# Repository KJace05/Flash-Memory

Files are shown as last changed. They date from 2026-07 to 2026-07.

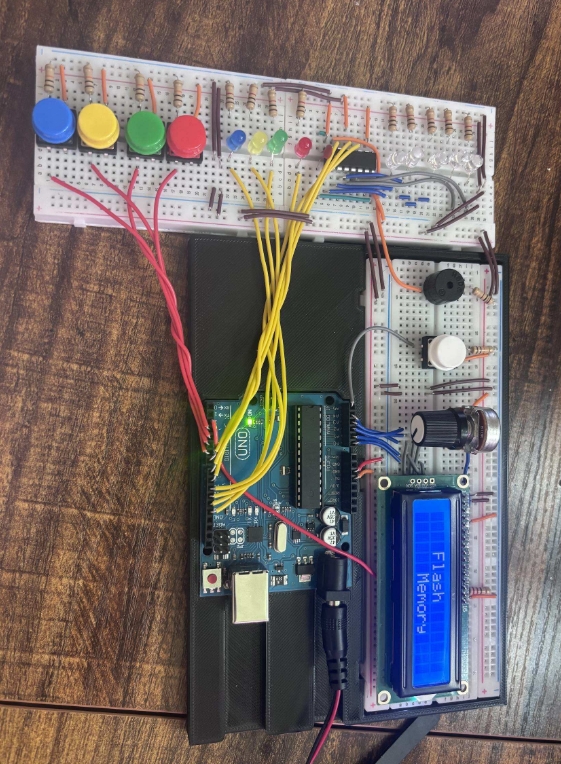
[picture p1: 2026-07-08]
content/breadboard overview.jpeg

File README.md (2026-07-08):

# Flash Memory

> An Arduino-based memory game inspired by Simon Says — built with C++ for the Arduino Uno.

## About

Flash Memory challenges players to watch a randomly generated sequence of colored LED flashes and recreate it by pressing the matching colored buttons in the correct order. The sequence grows longer with each level, testing both memory and focus.

A buzzer sounds with every LED flash during the sequence display, giving players an audio cue to count flashes by ear alongside the visual pattern.

---

##  Gameplay

1. **Watch** — colored LEDs flash a random sequence with an accompanying buzzer beep per flash
2. **Repeat** — press the matching colored buttons in the same order
3. **Progress** — complete the sequence correctly to advance to the next level
4. **Win** — complete all 5 levels

### Wrong Guess
- All 4 colored LEDs flash simultaneously
- Buzzer sounds to signal the incorrect answer
- A short delay prevents further input
- The same sequence replays automatically — unlimited attempts per level

### Replay Button
Forgot the sequence mid-guess? Press the dedicated replay button at any time during the input phase to rewatch the same sequence without generating a new one.

---

##  Levels

| Level | Sequence Length | Progress LED |
|---|---|---|
| 1 | 2 flashes | ⚪ |
| 2 | 3 flashes | ⚪⚪ |
| 3 | 4 flashes | ⚪⚪⚪ |
| 4 | 5 flashes | ⚪⚪⚪⚪ |
| 5 | 6 flashes | ⚪⚪⚪⚪⚪ |

Five white LEDs connected to a 74HC595 shift register light up one by one as each level is completed, giving a persistent visual indicator of progress.

---

## Randomization

Every game generates a unique sequence using the Arduino `EEPROM` library as a persistent seed generator. On each power cycle, the stored seed is read, incremented, and written back, ensuring a different sequence every playthrough, even across power cycles.

---

## Hardware

| Component | Quantity | Notes |
|---|---|---|
| Arduino Uno | 1 | Microcontroller |
| Colored LEDs | 4 | Red, Green, Yellow, Blue |
| Colored buttons | 4 | Matching colors |
| White LEDs | 5 | Level progress indicator |
| 74HC595 shift register | 1 | Drives white LEDs + buzzer |
| Active buzzer | 1 | Connected to Q0 on shift register |
| 16x2 LCD display | 1 | Shows title and game state |
| Replay button | 1 | Replays current sequence |
| Resistors | Various | Current limiting for LEDs |
| Potentiometer | 1 | Controls LCD brightness

---

##  Pin Map

| Pin | Assignment |
|-----|---|
| `2` | LCD D7 |
| `3` | Blue button |
| `4` | Yellow button |
| `5` | Green button |
| `6` | Red button |
| `7` | 74HC595 Clock |
| `8` | 74HC595 Latch |
| `9` | 74HC595 Data |
| `10` | Red LED |
| `11` | Green LED |
| `12` | Yellow LED |
| `13` | Blue LED |
| `A0` | LCD RS |
| `A1` | LCD Enable |
| `A2` | LCD D4 |
| `A3` | LCD D5 |
| `A4` | LCD D6 |
| `A5` | Replay button |

### 74HC595 Output Map
| Bit | Assignment |
|-----|---|
| Q0 | Buzzer |
| Q1–Q5 | White LEDs 1–5 |
| Q6–Q7 | Unused |

---

## Libraries

```cpp
#include <LiquidCrystal.h>   // LCD display control
#include <EEPROM.h>           // Persistent seed storage for randomization
```

---

## Technical Notes

- Sequence timing uses **`millis()`** for non-blocking LED flashing — the Arduino remains responsive during the display phase
- **`delay()`** is used selectively to gate player input at key moments (wrong guess lockout, level transition pause)
- The buzzer and white LEDs share the same 74HC595 — all shift register writes preserve the full byte state to prevent unintentional outputs
- `EEPROM.get()` / `EEPROM.put()` store a 4-byte `unsigned long` seed (0 to ~4 billion) for maximum sequence variety

---

## Getting Started

1. Wire components according to the pin map above
2. Install the Arduino IDE
3. Open `FlashMemory.ino`
4. Select **Arduino Uno** as the board
5. Upload and play

---

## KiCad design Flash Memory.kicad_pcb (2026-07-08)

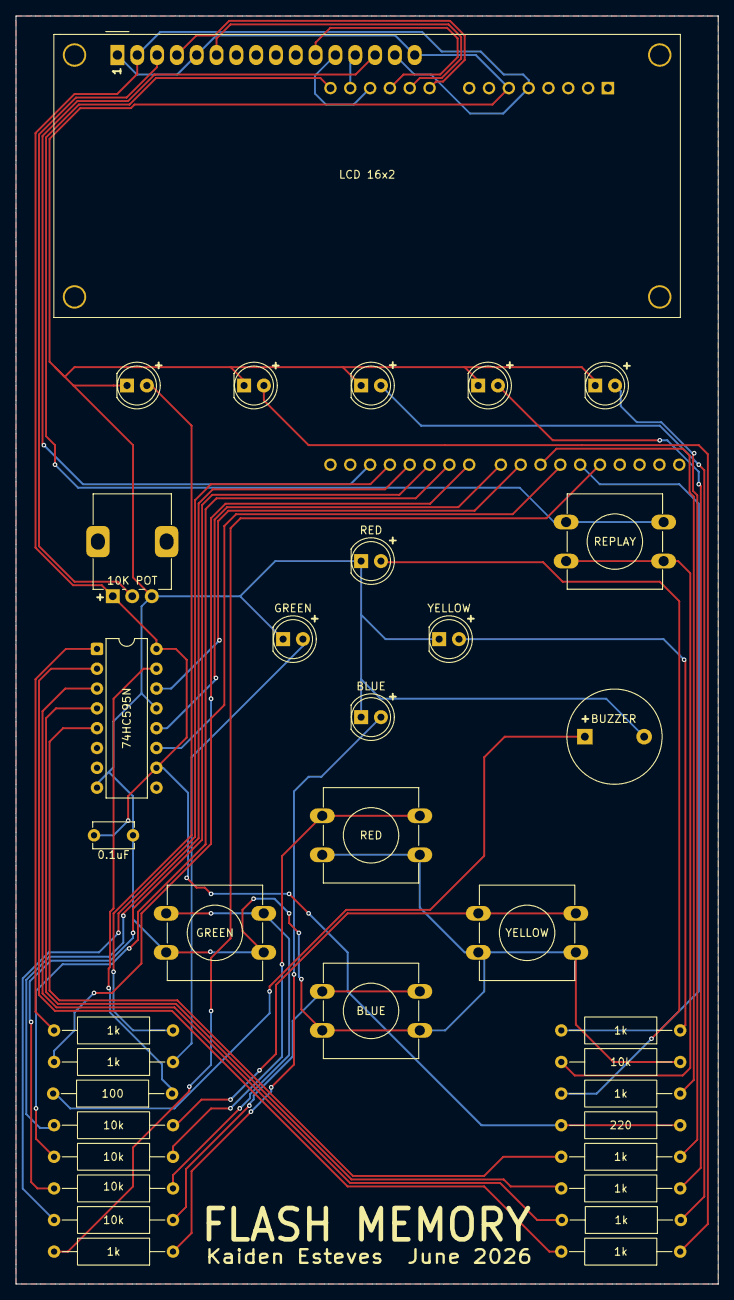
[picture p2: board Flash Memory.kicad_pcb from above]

Board: 2 copper layers, 90.0 x 162.5 mm, 36 parts (1 on the bottom side), 42 nets.

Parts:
74HC595N: 74HC595; DIP-16_W7.62mm
Arduino1: Arduino_UNO_R3
BLUE: LED; LED_D5.0mm
BUZZER: Buzzer; Buzzer_12x9.5RM7.6
Button_B1: SW_Push; SW_PUSH-12mm
Button_G1: SW_Push; SW_PUSH-12mm
Button_R1: SW_Push; SW_PUSH-12mm
Button_Y1: SW_Push; SW_PUSH-12mm
C1: .1uf; C_Disc_D5.1mm_W3.2mm_P5.00mm
GREEN: LED; LED_D5.0mm
LCD 16x2: WC1602A
Level_1, Level_2, Level_3, Level_4, Level_5: LED; LED_D5.0mm
Potentiometer1: R_Potentiometer; Potentiometer_Alps_RK09K_Single_Vertical
RED: LED; LED_D5.0mm
REPLAY: SW_Push; SW_PUSH-12mm
YELLOW: LED; LED_D5.0mm
r_blue1: 1k; R_Axial_DIN0309_L9.0mm_D3.2mm_P15.24mm_Horizontal
r_butt_blue1: 10k; R_Axial_DIN0309_L9.0mm_D3.2mm_P15.24mm_Horizontal
r_butt_green1: 10k; R_Axial_DIN0309_L9.0mm_D3.2mm_P15.24mm_Horizontal
r_butt_red1: 10k; R_Axial_DIN0309_L9.0mm_D3.2mm_P15.24mm_Horizontal
r_butt_yellow1: 10k; R_Axial_DIN0309_L9.0mm_D3.2mm_P15.24mm_Horizontal
r_buzz1: 100; R_Axial_DIN0309_L9.0mm_D3.2mm_P15.24mm_Horizontal
r_green1: 1k; R_Axial_DIN0309_L9.0mm_D3.2mm_P15.24mm_Horizontal
r_l1, r_l2, r_l3, r_l4, r_l5: 1k; R_Axial_DIN0309_L9.0mm_D3.2mm_P15.24mm_Horizontal
r_pot1: 220; R_Axial_DIN0309_L9.0mm_D3.2mm_P15.24mm_Horizontal
r_red1: 1k; R_Axial_DIN0309_L9.0mm_D3.2mm_P15.24mm_Horizontal
r_replay1: 10k; R_Axial_DIN0309_L9.0mm_D3.2mm_P15.24mm_Horizontal
r_yellow1: 1k; R_Axial_DIN0309_L9.0mm_D3.2mm_P15.24mm_Horizontal

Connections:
+5V: 74HC595N.10 (~SRCLR), 74HC595N.16 (VCC), Arduino1.5 (+5V), C1.1, LCD 16x2.2 (VDD), LCD 16x2.15 (LED(+)), Potentiometer1.1, r_pot1.1, r_pot1.2
GND: 74HC595N.8 (GND), 74HC595N.13 (~OE), Arduino1.6 (GND), BLUE.1 (K), BUZZER.2 (-), Button_B1.2, Button_G1.2, Button_R1.2, Button_Y1.2, C1.2, GREEN.1 (K), LCD 16x2.1 (VSS), LCD 16x2.5 (R/W), LCD 16x2.16 (LED(-)), Level_1.1 (K), Level_2.1 (K), Level_3.1 (K), Level_4.1 (K), Level_5.1 (K), Potentiometer1.3, RED.1 (K), YELLOW.1 (K), r_replay1.1
unnamed: Arduino1.9 (A0), LCD 16x2.4 (RS)
unnamed: Arduino1.10 (A1), LCD 16x2.6 (E)
unnamed: Arduino1.11 (A2), LCD 16x2.11 (D4)
unnamed: Arduino1.12 (A3), LCD 16x2.12 (D5)
unnamed: Arduino1.17 (D2), LCD 16x2.14 (D7)
unnamed: Arduino1.18 (D3), r_butt_blue1.2
unnamed: Arduino1.19 (D4), r_butt_yellow1.2
unnamed: Arduino1.20 (D5), r_butt_green1.2
unnamed: Arduino1.21 (D6), r_butt_red1.2
unnamed: 74HC595N.11 (SRCLK), Arduino1.22 (D7)
unnamed: 74HC595N.12 (RCLK), Arduino1.23 (D8)
unnamed: 74HC595N.14 (SER), Arduino1.24 (D9)
unnamed: Arduino1.25 (D10), r_red1.1
unnamed: Arduino1.26 (D11), r_green1.2
unnamed: Arduino1.27 (D12), r_yellow1.2
unnamed: Arduino1.28 (D13), r_blue1.2
unnamed: Arduino1.14 (SCL/A5), REPLAY.1
unnamed: BUZZER.1 (+), r_buzz1.2
unnamed: BLUE.2 (A), r_blue1.1
unnamed: Button_B1.1, r_butt_blue1.1
unnamed: Button_G1.1, r_butt_green1.1
unnamed: Button_R1.1, r_butt_red1.1
unnamed: Button_Y1.1, r_butt_yellow1.1
unnamed: GREEN.2 (A), r_green1.1
unnamed: 74HC595N.15 (QA), r_buzz1.1
unnamed: 74HC595N.1 (QB), r_l1.2
unnamed: 74HC595N.2 (QC), r_l2.2
unnamed: 74HC595N.3 (QD), r_l3.2
unnamed: 74HC595N.4 (QE), r_l4.2
unnamed: 74HC595N.5 (QF), r_l5.2
unnamed: Arduino1.13 (SDA/A4), LCD 16x2.13 (D6)
unnamed: LCD 16x2.3 (VO), Potentiometer1.2
unnamed: Level_1.2 (A), r_l1.1
unnamed: Level_2.2 (A), r_l2.1
unnamed: Level_3.2 (A), r_l3.1
unnamed: Level_4.2 (A), r_l4.1
unnamed: Level_5.2 (A), r_l5.1
unnamed: RED.2 (A), r_red1.2
unnamed: REPLAY.2, r_replay1.2
unnamed: YELLOW.2 (A), r_yellow1.1

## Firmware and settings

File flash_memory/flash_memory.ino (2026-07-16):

#include <LiquidCrystal.h>
#include <EEPROM.h>

// Button initalization
#define R_BUTT_PIN 6
#define G_BUTT_PIN 5
#define Y_BUTT_PIN 4
#define B_BUTT_PIN 3
#define REPLAY_BUTT_PIN A5


// LED initalization
#define R_LED 10
#define G_LED 11
#define Y_LED 12
#define B_LED 13


// IC LED & Buzzer initalization
#define IC_LEVEL_DATA 9
#define IC_LEVEL_LATCH 8
#define IC_LEVEL_CLOCK 7


// setting up game state for main loop
enum GameState {SHOW_SEQUENCE, WAIT_FOR_INPUT, LEVEL_COMPLETE, GAME_WON}; // for switch statement
GameState state_of_game = SHOW_SEQUENCE; //begin at showing sequence


//colored LEDS
int colored_leds[] = {10,11,12,13}; // colored LEDS
int level = 0; // start on level 1
bool level_over = false;
int total_flashing = 2; // initally, 2LEDS will flash. 6 max
int sequence[6] = {};
bool sequence_made = false;
int flash_index = 0;
bool led_on = false;
unsigned long last_LED_flash = millis();
unsigned long flash_delay = 300;


// White LEDS
int level_leds[] = {1,2,3,4,5};
int level_led = 1;


// BUTTONS
int buttons[] = {6,5,4,3}; //buttons
unsigned long last_debounce_time[4] = {0,0,0,0};
unsigned long debounce_delay = 25;
bool button_state[4] = {LOW,LOW,LOW,LOW};
bool last_button_state[4] = {LOW,LOW,LOW,LOW};


//replay button
int replay_button = A5;
bool replay_state = LOW;
bool last_replay_state = LOW;
unsigned long last_replay_debounce_time = 0;


// LCD screen
LiquidCrystal lcd{A0,A1,A2,A3,A4,2};
int row = 0;
int col = 0;


//player guess
int guess[8] = {};
int guess_index = 0;


//initalial setup
void setup()
{
 // Serial.begin(115200);
  //inialize random seed for sequencing
  unsigned long seed = 0;
  EEPROM.get(0, seed);
  if (seed == 0xFFFFFFFF) seed = 0; // handle blank EEPROM on first boot
  seed++;
  EEPROM.put(0, seed);
  randomSeed(seed);
  // burn through initial similar values
  for (int i = 0; i < 10; i++)
  {
      random(10, 14);
  }

  lcd.begin(16,2);
  show_title();

  //initalize colored LEDS
  for (int i = 0; i < 4; i++)
  {
    pinMode(colored_leds[i], OUTPUT);
  }

  //initalize buttons
  for (int i = 0; i < 4; i++)
  {
    pinMode(buttons[i], INPUT_PULLUP);
  }

  //inialitze replay button
  pinMode(replay_button, INPUT_PULLUP);


  //initalize level and buzzer IC
  pinMode(IC_LEVEL_DATA, OUTPUT);
  pinMode(IC_LEVEL_LATCH, OUTPUT);
  pinMode(IC_LEVEL_CLOCK, OUTPUT);

  // clear all IC outputs on startup
  digitalWrite(IC_LEVEL_LATCH, LOW);
  shiftOut(IC_LEVEL_DATA, IC_LEVEL_CLOCK, MSBFIRST, B00000000);
  digitalWrite(IC_LEVEL_LATCH, HIGH);

  delay(2000);
  last_LED_flash = millis(); // reset timer after delay
}


//display game title on LCD
void show_title()
{
  lcd.clear();
  lcd.setCursor(4,0);
  lcd.print("Flash");

  lcd.setCursor(6,1);
  lcd.print("Memory");
}

//randomly flash LEDS / SHOW SEQUENCE
void flash_leds()
{
  //stop showing sequence
  if (level_over)
  {
    return;
  }

  //adds pins to squence once
  if(!sequence_made)
  {
    //add LED pins to sequence
    for (int i = 0; i < total_flashing; i++)
    {
      sequence[i] = random(10,14); // colored LEDs are pins 10,11,12,13
    }
    sequence_made = true;
  }
  //time
  unsigned time_now = millis(); //current time


  //flash those led pins
  if(time_now - last_LED_flash >= flash_delay)
  {
    last_LED_flash = time_now;
    //if the LED is on, turn it off
    if(led_on)
    {
        digitalWrite(sequence[flash_index], LOW); // turn colored off
        led_on = false;
        flash_index++; // move to next LED


        //when completed the sequence
        if(flash_index >= total_flashing)
        {
          flash_index = 0;
          level_over = true;
        }
    }
    else // if LED is off, turn it on 
    {
    digitalWrite(sequence[flash_index], HIGH);
    led_on = true;
    buzzer_sound();
    }
  }
}


// WAIT FOR INPUT
void player_input()
{
  //stop if level is complete
  if (!level_over)
  {
    return;
  }

  //check state of each of the 4 buttons
  for (int i = 0; i < 4; i++)
  {
    bool reading = digitalRead(buttons[i]); //read raw electrical state of button, unverified 

    // check if the buttons reading changed
    if (reading != last_button_state[i])
    {
      last_debounce_time[i] = millis();
    }

    // check if button reading was stable
    if (millis() - last_debounce_time[i] > debounce_delay)
    {

      // if new state
      if (reading != button_state[i])
      {
        button_state[i] = reading; //confirmed state

        if (button_state[i] == LOW) //if high, go to handle function
        {
          handle_button_press(i);
        }
      }
    }
    last_button_state[i] = reading; //store raw reading for next comparison 
  } 
}


// compare player guess to sequence
void handle_button_press(int button_index)
{
  //Serial.print("PRESS DETECTED on button ");
 // Serial.println(button_index);

  int pressed_led = colored_leds[button_index];

  // flash player input
  digitalWrite(pressed_led, HIGH);
  delay(100); //delay doesnt cause much interference with program
  digitalWrite(pressed_led, LOW);

  //comparison
  if(pressed_led == sequence[guess_index])
  {
    guess_index++;

    //level complete
    if (guess_index >= total_flashing)
    {
      //won game
      if (level >= 4)
      {
        // light all 5 LEDs on win
        level = 5;
        initalize_level_leds();

        state_of_game = GAME_WON;
        lcd.clear();
        lcd.setCursor(5,0);
        lcd.print("YOU");

        lcd.setCursor(7,1);
        lcd.print("WIN!");
        return;
      }

      level++;
      total_flashing++;
      guess_index = 0;
      flash_index = 0;
      led_on = false;
      level_over = false;
      sequence_made = false;
      last_LED_flash = millis(); 
      state_of_game = SHOW_SEQUENCE;
     // Serial.println("level complete");

      initalize_level_leds(); // update IC output

      delay(1000); //delay to stop all input from user 
    }
  }
  else // wrong guess
  {
    //Serial.print("Wrong button: ");
    //Serial.println(pressed_led);
    buzzer_sound(); // buzzes when wrong

    // flash LEDS when wrong guess
    for(int i = 0 ; i < 4; i++)
    {
      digitalWrite(colored_leds[i], HIGH);
    }
    delay(100);
    for(int i = 0 ; i < 4; i++)
    {
      digitalWrite(colored_leds[i], LOW);
    }

    //replay sequence
    guess_index = 0;
    flash_index = 0;
    led_on = false;
    level_over = false;
    last_LED_flash = millis(); 
    state_of_game = SHOW_SEQUENCE;
    delay(1000);
  }
}


// CHECK REPLAY
void replay_sequence()
{


  // rest of function...
  //only allow if waiting for player response
  if (state_of_game != WAIT_FOR_INPUT)
  {
    return;
  }

  bool reading = digitalRead(replay_button); //read current button state

  // if current read is different than last, change time
  if(reading != last_replay_state)
  {
    last_replay_debounce_time = millis();
  }

  if(millis() - last_replay_debounce_time > debounce_delay)
  {
    if(reading != replay_state)
    {
      replay_state = reading;

      // if clicked, replay sequence
      if(replay_state == LOW)
      {
        guess_index = 0;
        flash_index = 0;
        led_on = false;
        level_over = false;
        last_LED_flash = millis();
        state_of_game = SHOW_SEQUENCE;
      }
    }
  }
  last_replay_state = reading; //store to compare later
}


//LEVEL LEDS
void initalize_level_leds()
{
  byte led_data = 0; // start data chain with 0

  for(int i = 0; i < level; i++)
  {
    bitSet(led_data, level_leds[i] ); //turn ON the bit at that position.
  }


  //send data to IC
  digitalWrite(IC_LEVEL_LATCH, LOW); //wait for all input
  shiftOut(IC_LEVEL_DATA, IC_LEVEL_CLOCK, MSBFIRST, led_data); // shift data to clock by most significant bit first
  digitalWrite(IC_LEVEL_LATCH, HIGH); // release all bits
}


//BUZZER
void buzzer_sound()
{
  byte buzzer_data = 0;

  //preserve white leds
  for(int i = 0; i < level; i++)
  {
    bitSet(buzzer_data, level_leds[i]);
  }

  bitSet(buzzer_data, 0); // on
  digitalWrite(IC_LEVEL_LATCH, LOW);
  shiftOut(IC_LEVEL_DATA, IC_LEVEL_CLOCK, MSBFIRST, buzzer_data);
  digitalWrite(IC_LEVEL_LATCH, HIGH);
  
  delay(100);

  bitClear(buzzer_data, 0); // off
  digitalWrite(IC_LEVEL_LATCH, LOW);
  shiftOut(IC_LEVEL_DATA, IC_LEVEL_CLOCK, MSBFIRST, buzzer_data);
  digitalWrite(IC_LEVEL_LATCH, HIGH);
}


//main game
void loop()
{
  replay_sequence();   //always listening

  //main loop
  switch(state_of_game)
  {
    case SHOW_SEQUENCE:
     // Serial.println(level);
      flash_leds();
      if(level_over)
      {
        state_of_game = WAIT_FOR_INPUT;
      }
      break;

    case WAIT_FOR_INPUT:
      player_input();
      break;

    case LEVEL_COMPLETE:
      level++;
      total_flashing++; // 2..3..4..5..6
      state_of_game = SHOW_SEQUENCE;
      break;

    case GAME_WON:
      break;
    default:
      break;
  }

}
